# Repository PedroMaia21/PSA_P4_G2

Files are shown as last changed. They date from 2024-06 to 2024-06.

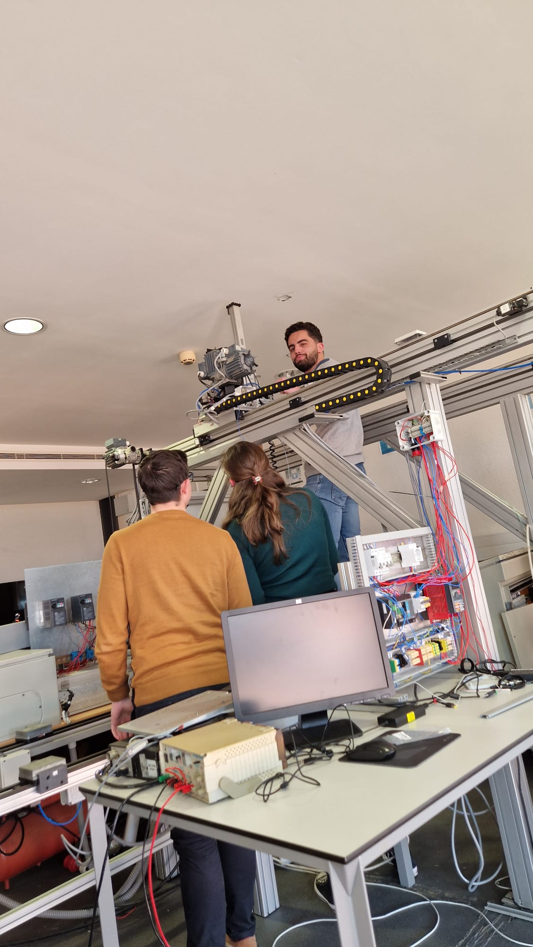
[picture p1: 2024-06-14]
pagina_web/portico24/portico.jpeg

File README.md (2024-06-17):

# PSA_P4_G2
## Descrição
O objetivo principal deste projeto foi realizar o retrofitting de um pórtico cartesiano existente no Laboratório de Sistemas Flexíveis de Produção, trazendo-o de volta ao estado de funcionamento original. Especificamente, procurámos garantir o funcionamento dos eixos Y e Z que anteriormente não estavam operacionais.

### Objetivos do Projeto
 - Avaliação do estado do pórtico cartesiano e identificação dos problemas a resolver.
 - Definição das soluções técnicas a serem implementadas.
 - Execução das modificações e melhorias através do desenvolvimento de um quadro elétrico e da programação de um PLC, um microcontrolador e uma aplicação Web.
 - Realização de testes rigorosos e simulações para validar as melhorias implementadas.

### Resultados Alcançados
 - **Pórtico com todos os eixos funcionais:** O pórtico cartesiano agora possui todos os eixos (X, Y e Z) operacionais.
 - **Novas funcionalidades:** Implementação de controlo remoto via aplicação Web.
 - **Melhorias na performance e funcionamento:** O sistema foi aprimorado para atender melhor às necessidades operacionais futuras.

## Uso
Conecte todos os componentes conforme descrito na documentação.

Carregue o código no PLC e no microcontrolador. (Apenas é necessário editar o nome da rede de internet a usar e a palavra-passe no microcontrolador)

Acesse a aplicação Web para controlar remotamente o pórtico cartesiano. Garanta que o node-red se encontra a correr.

### Contacto
Em caso de estrema necessidade, contactar pedroabmaia@hotmail.com

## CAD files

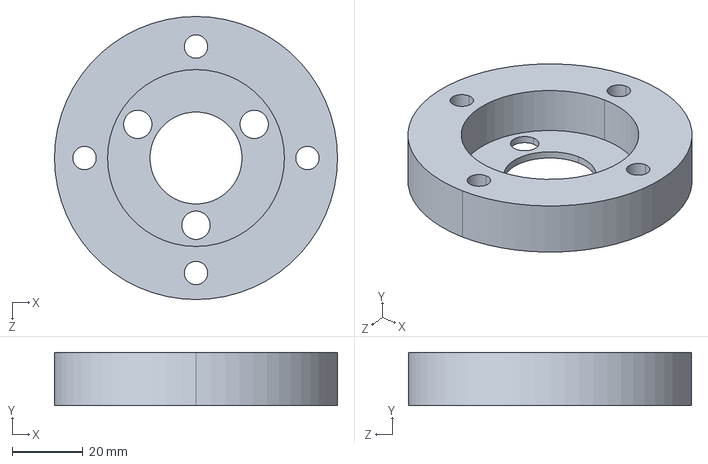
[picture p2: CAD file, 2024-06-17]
projeto_mecânico/Peça encoder.STEP
80.0 x 15.0 x 80.0 mm

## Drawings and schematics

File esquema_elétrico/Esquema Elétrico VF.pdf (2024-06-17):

Título / Frontispício | = 0

3810-1932

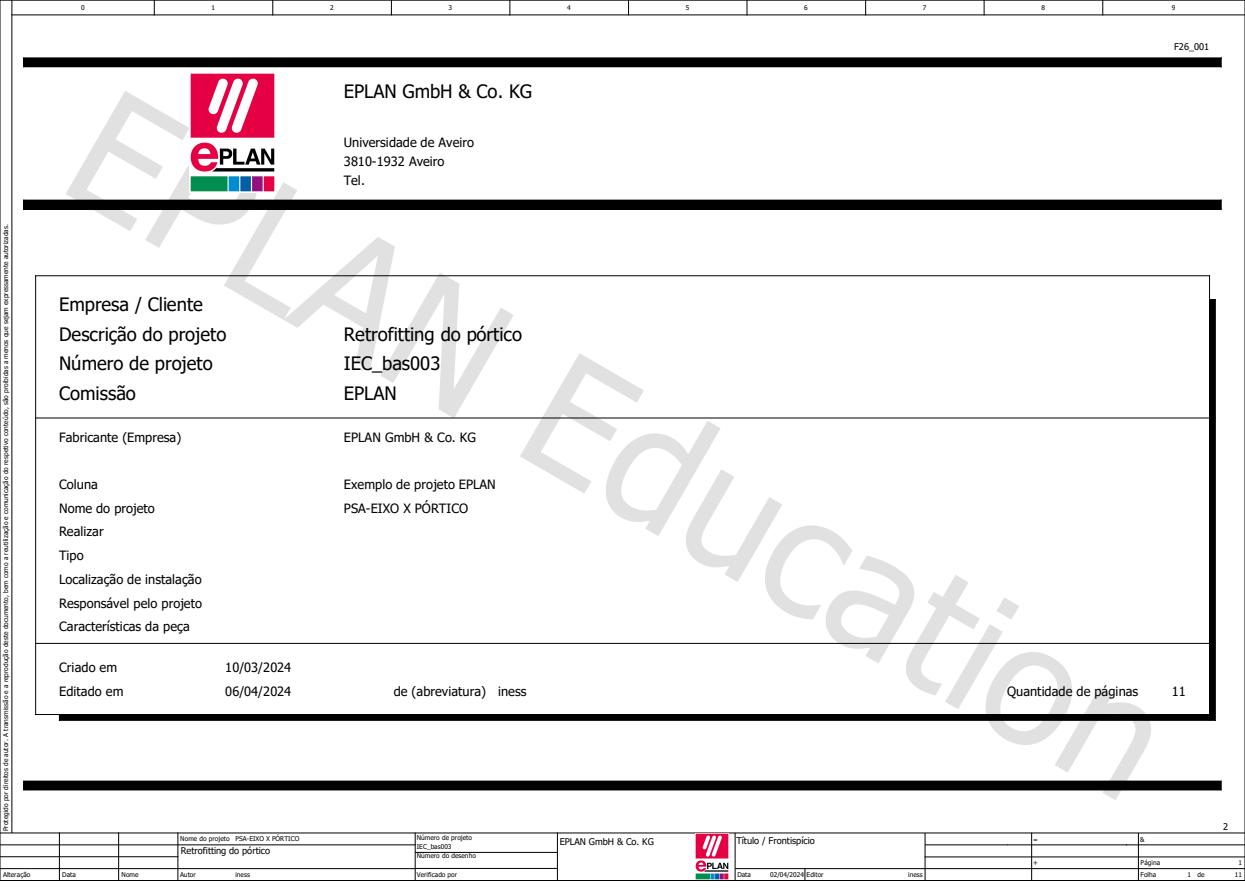
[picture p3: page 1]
Folha; de Retrofitting do pórtico; Editor IEC_bas003 Data; Data; iness 1; Alteração; Nome; EPLAN GmbH & Co. KG; Página; 1 PSA-EIXO X PÓRTICO; Verificado por Nome do projeto; Número do desenho Número de projeto Autor; iness Protegido por direitos de autor. A transmissão e a reprodução deste documento, bem como a reutilização e comunicação do respetivo conteúdo, são proibidas a menos que sejam expressamente autorizadas.; Descrição do projeto; Retrofitting do pórtico; Editado em; IEC_bas003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

EPLAN GmbH & Co. KG

Universidade de Aveiro

Empresa / Cliente
Número de projeto
Comissão

Coluna
Realizar
Tipo
Localização de instalação
Responsável pelo projeto
Características da peça

Exemplo de projeto EPLAN

Quantidade de páginas

Página | Descrição da página | Campo suplementar da página | Data | Editor | X
/1 | | | 02/04/2024 | iness Título / Frontispício | X

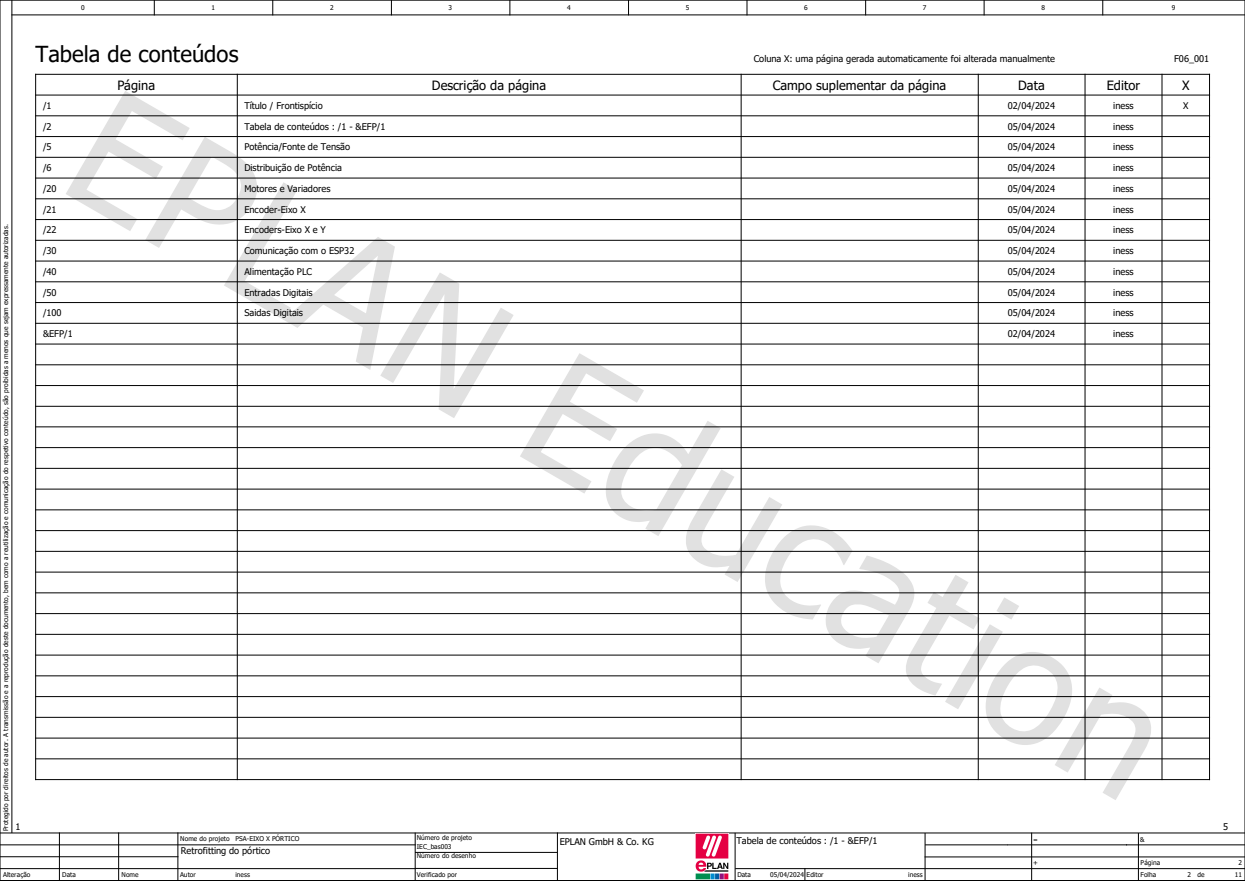
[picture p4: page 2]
Alteração; Nome; Verificado por Nome do projeto; Número do desenho Número de projeto Autor; iness Protegido por direitos de autor. A transmissão e a reprodução deste documento, bem como a reutilização e comunicação do respetivo conteúdo, são proibidas a menos que sejam expressamente autorizadas.

Tabela de conteúdos

Coluna X: uma página gerada automaticamente foi alterada manualmente

/2 | | | 05/04/2024 | iness Tabela de conteúdos : /1 - &EFP/1
/5 | | | 05/04/2024 | iness Potência/Fonte de Tensão
/6 | | | 05/04/2024 | iness Distribuição de Potência
/20 | Motores e Variadores | | 05/04/2024 | iness
/21 | Encoder-Eixo X | | 05/04/2024 | iness
/22 | Encoders-Eixo X e Y | | 05/04/2024 | iness
/30 | Comunicação com o ESP32 | | 05/04/2024 | iness
/40 | Alimentação PLC | | 05/04/2024 | iness
/50 | Entradas Digitais | | 05/04/2024 | iness
/100 | Saidas Digitais | | 05/04/2024 02/04/2024 | iness &EFP/1 iness

EPLAN GmbH & Co. KG | Editor 1 Tabela de conteúdos : /1 - &EFP/1 Data iness | = | Folha de Retrofitting do pórtico 2 PSA-EIXO X PÓRTICO

IEC_bas003 Data | | | | & + Página

5Q1

5F1

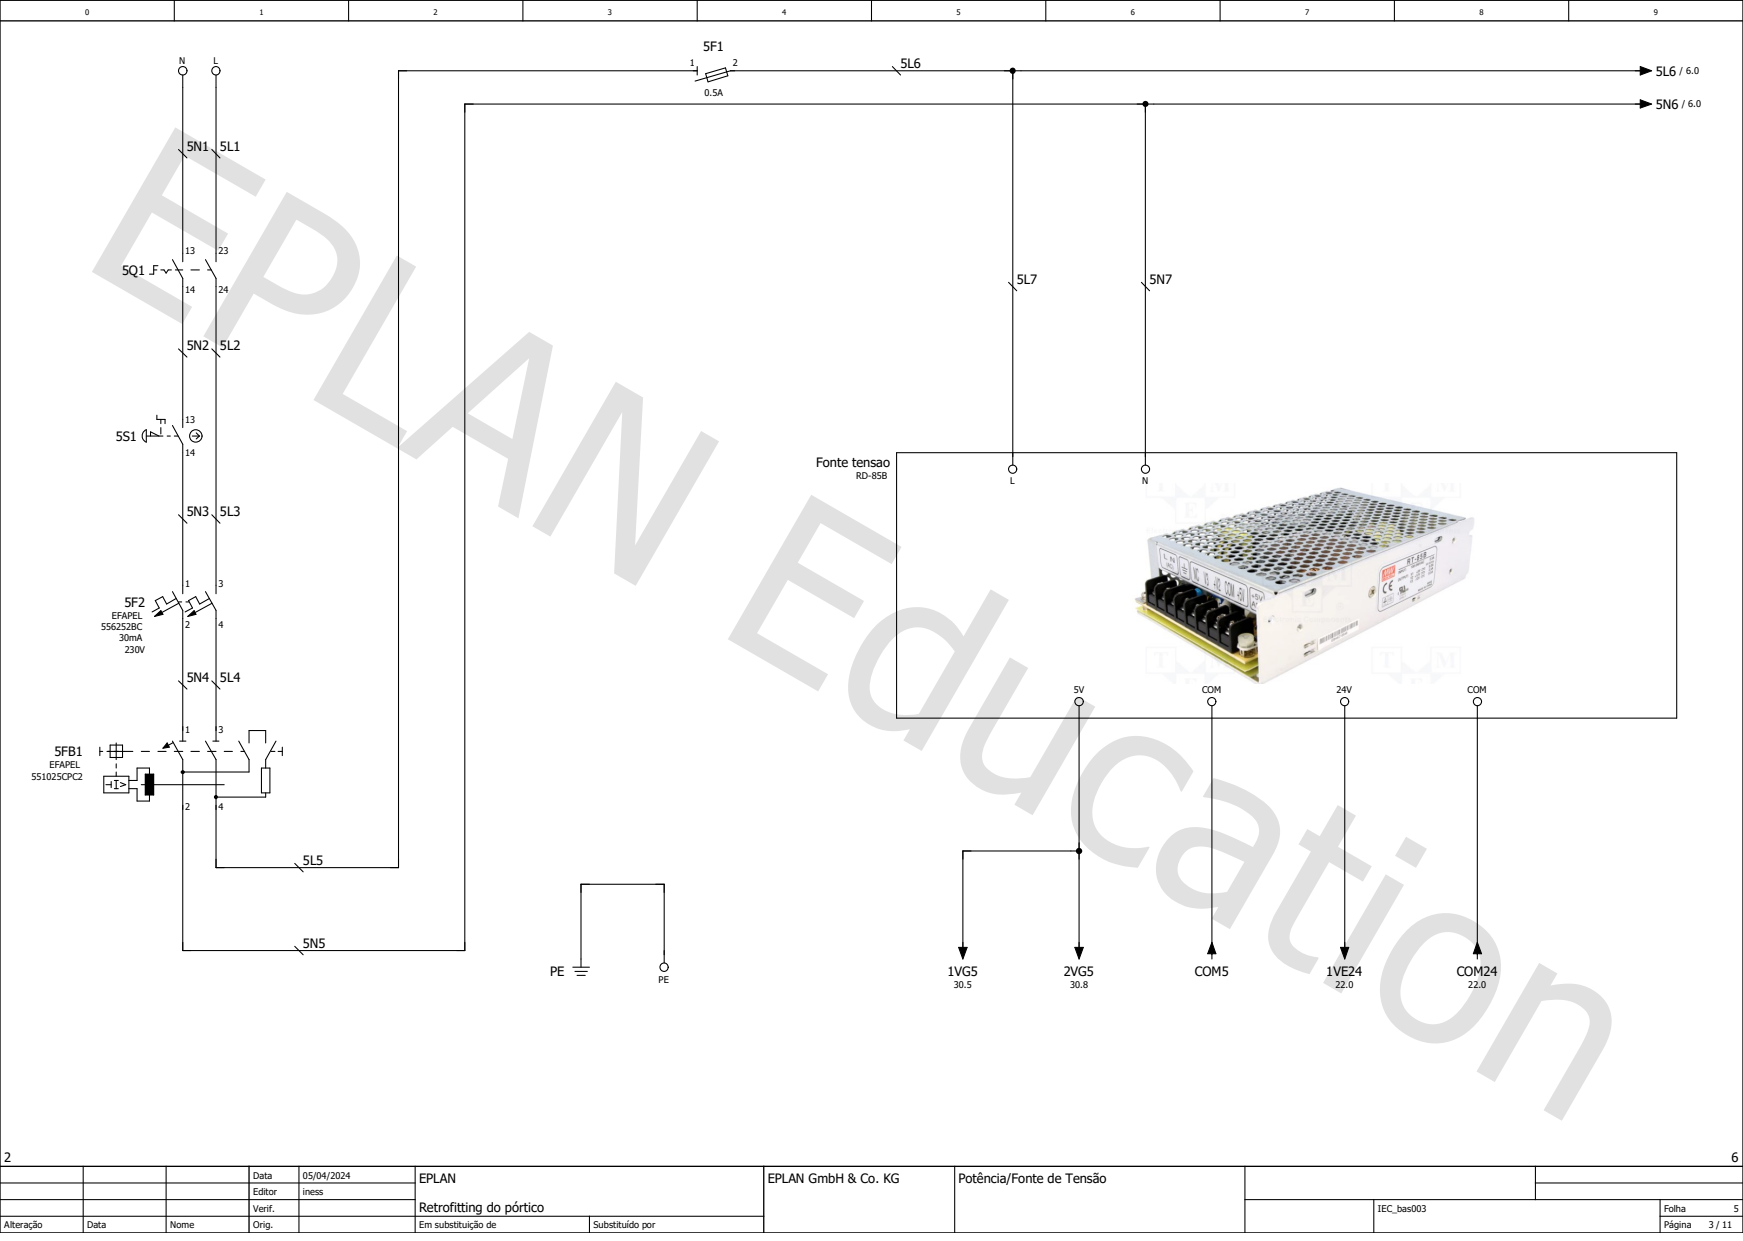
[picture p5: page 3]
Folha Página Retrofitting do pórtico Editor 2; Orig.; IEC_bas003 EPLAN; Verif.; Em substituição de; Fonte tensao RD-85B; COM; 5FB1 EFAPEL; 551025CPC2; 5F2 EFAPEL; 22.0 COM5; COM24

05/04/2024 | Substituído por | EPLAN GmbH & Co. KG | Potência/Fonte de Tensão

Data | iness Data

Alteração | Nome | 3 / 11

6FC1 | /6.1

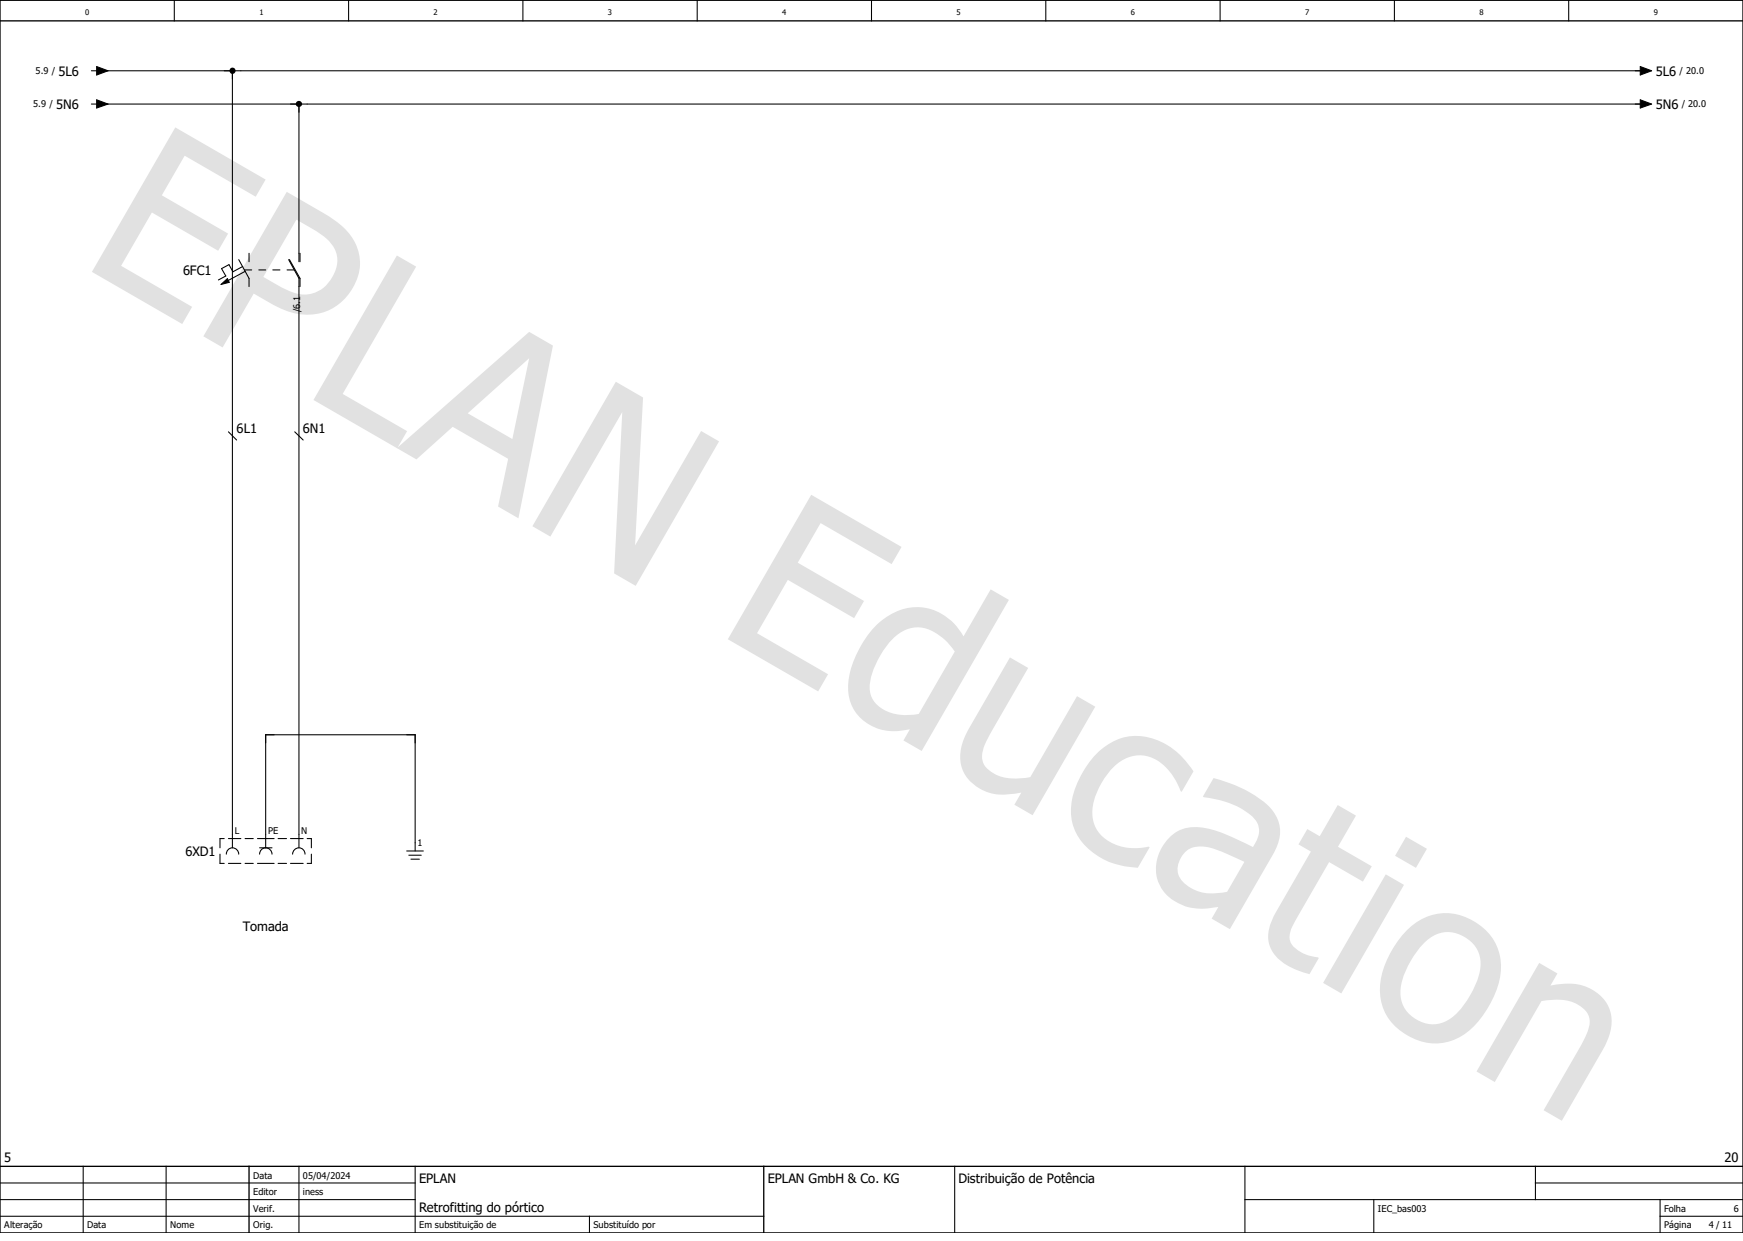
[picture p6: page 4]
Folha Página Retrofitting do pórtico Editor 5; Orig.; IEC_bas003 EPLAN; Verif.; Em substituição de; Tomada

05/04/2024 | Substituído por | EPLAN GmbH & Co. KG | Distribuição de Potência

Data | iness Data

Alteração | Nome | 4 / 11

## -20FC1 EFAPEL

20L1

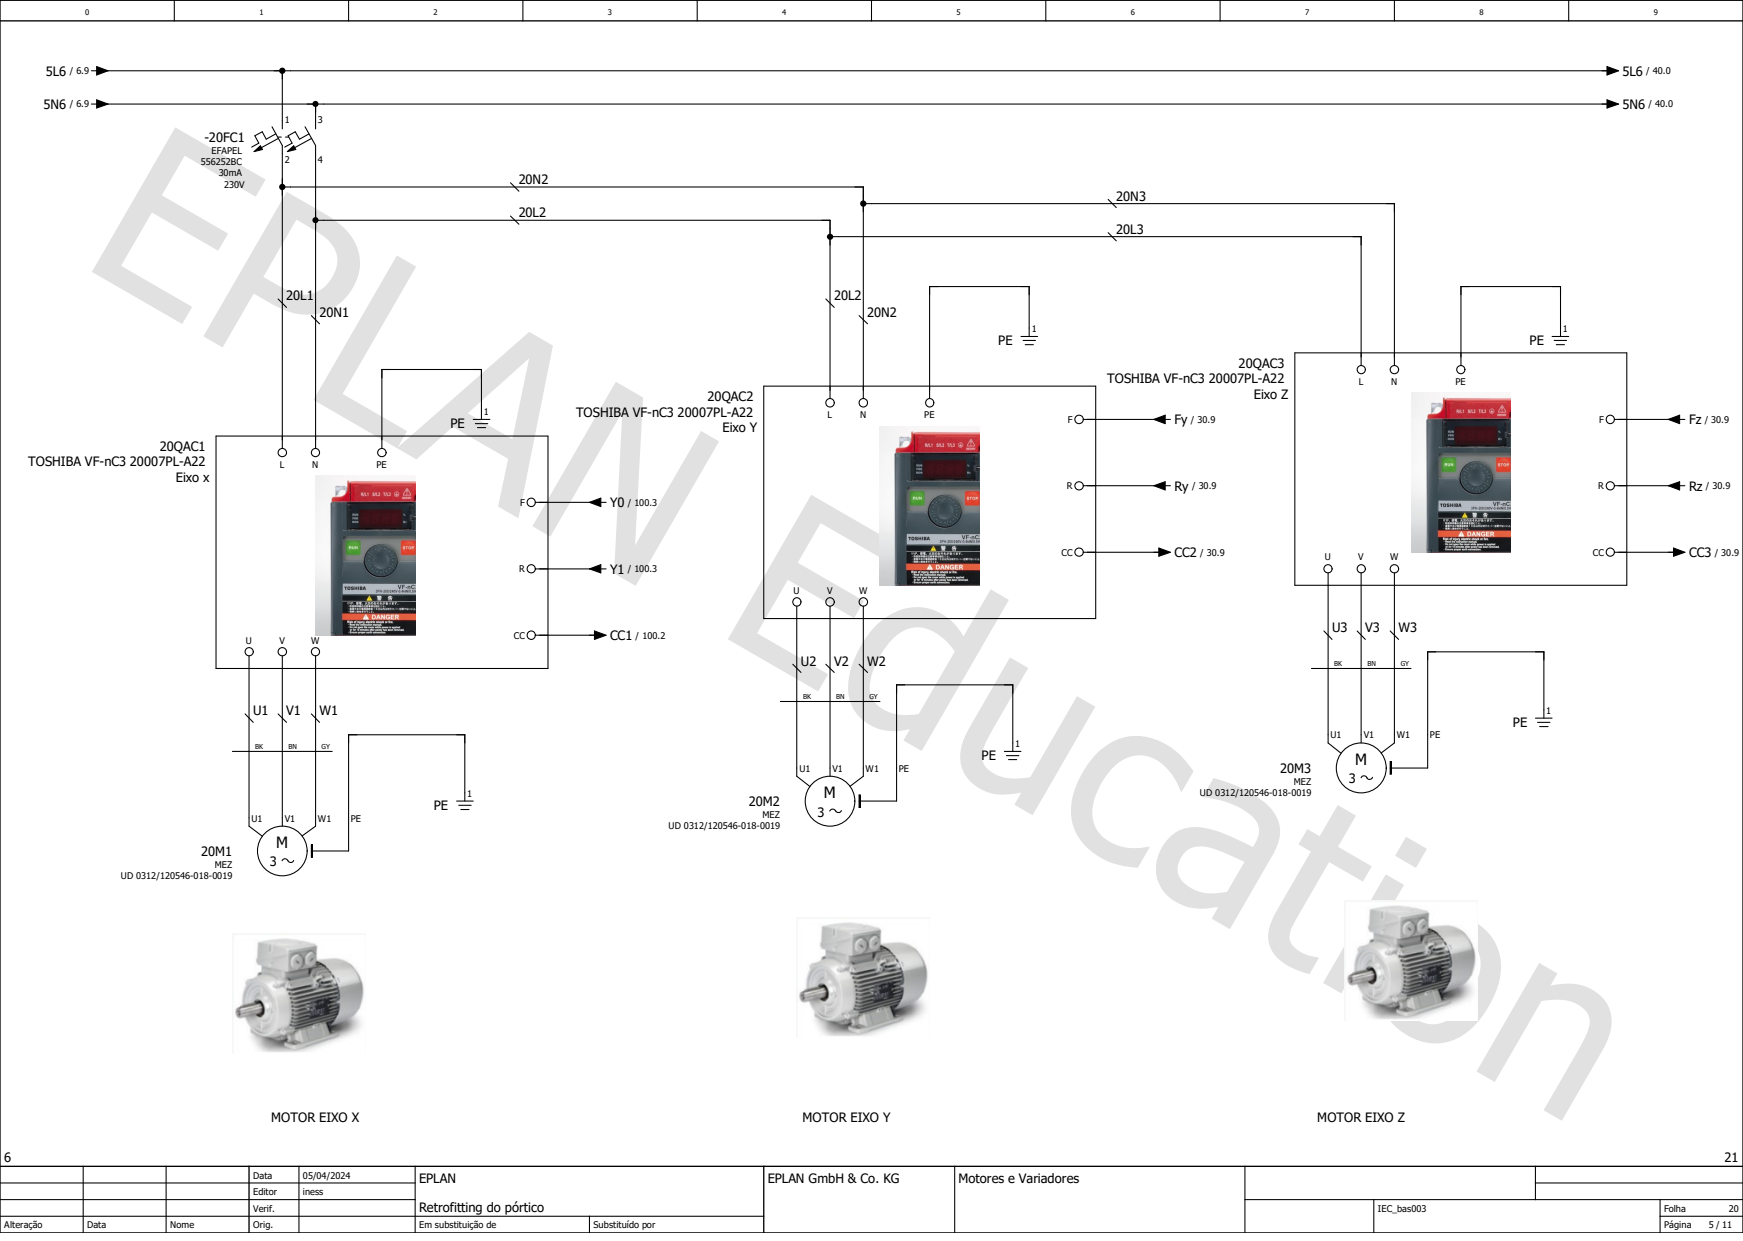
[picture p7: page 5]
Folha Página Retrofitting do pórtico Editor 6; Orig.; IEC_bas003 EPLAN; Verif.; Em substituição de; 5 / 11 MOTOR EIXO X; MOTOR EIXO Y; MOTOR EIXO Z; 20QAC1 TOSHIBA VF-nC3 20007PL-A22; Eixo x; 20M1 MEZ; 20M2 MEZ; 20QAC2 TOSHIBA VF-nC3 20007PL-A22; Eixo Y; 20M3 MEZ; 20QAC3 TOSHIBA VF-nC3 20007PL-A22 Eixo Z

05/04/2024 | Substituído por | EPLAN GmbH & Co. KG | Motores e Variadores

Data | iness Data

Alteração | Nome

2VE24 / 21.9

2VE24 / 21.0

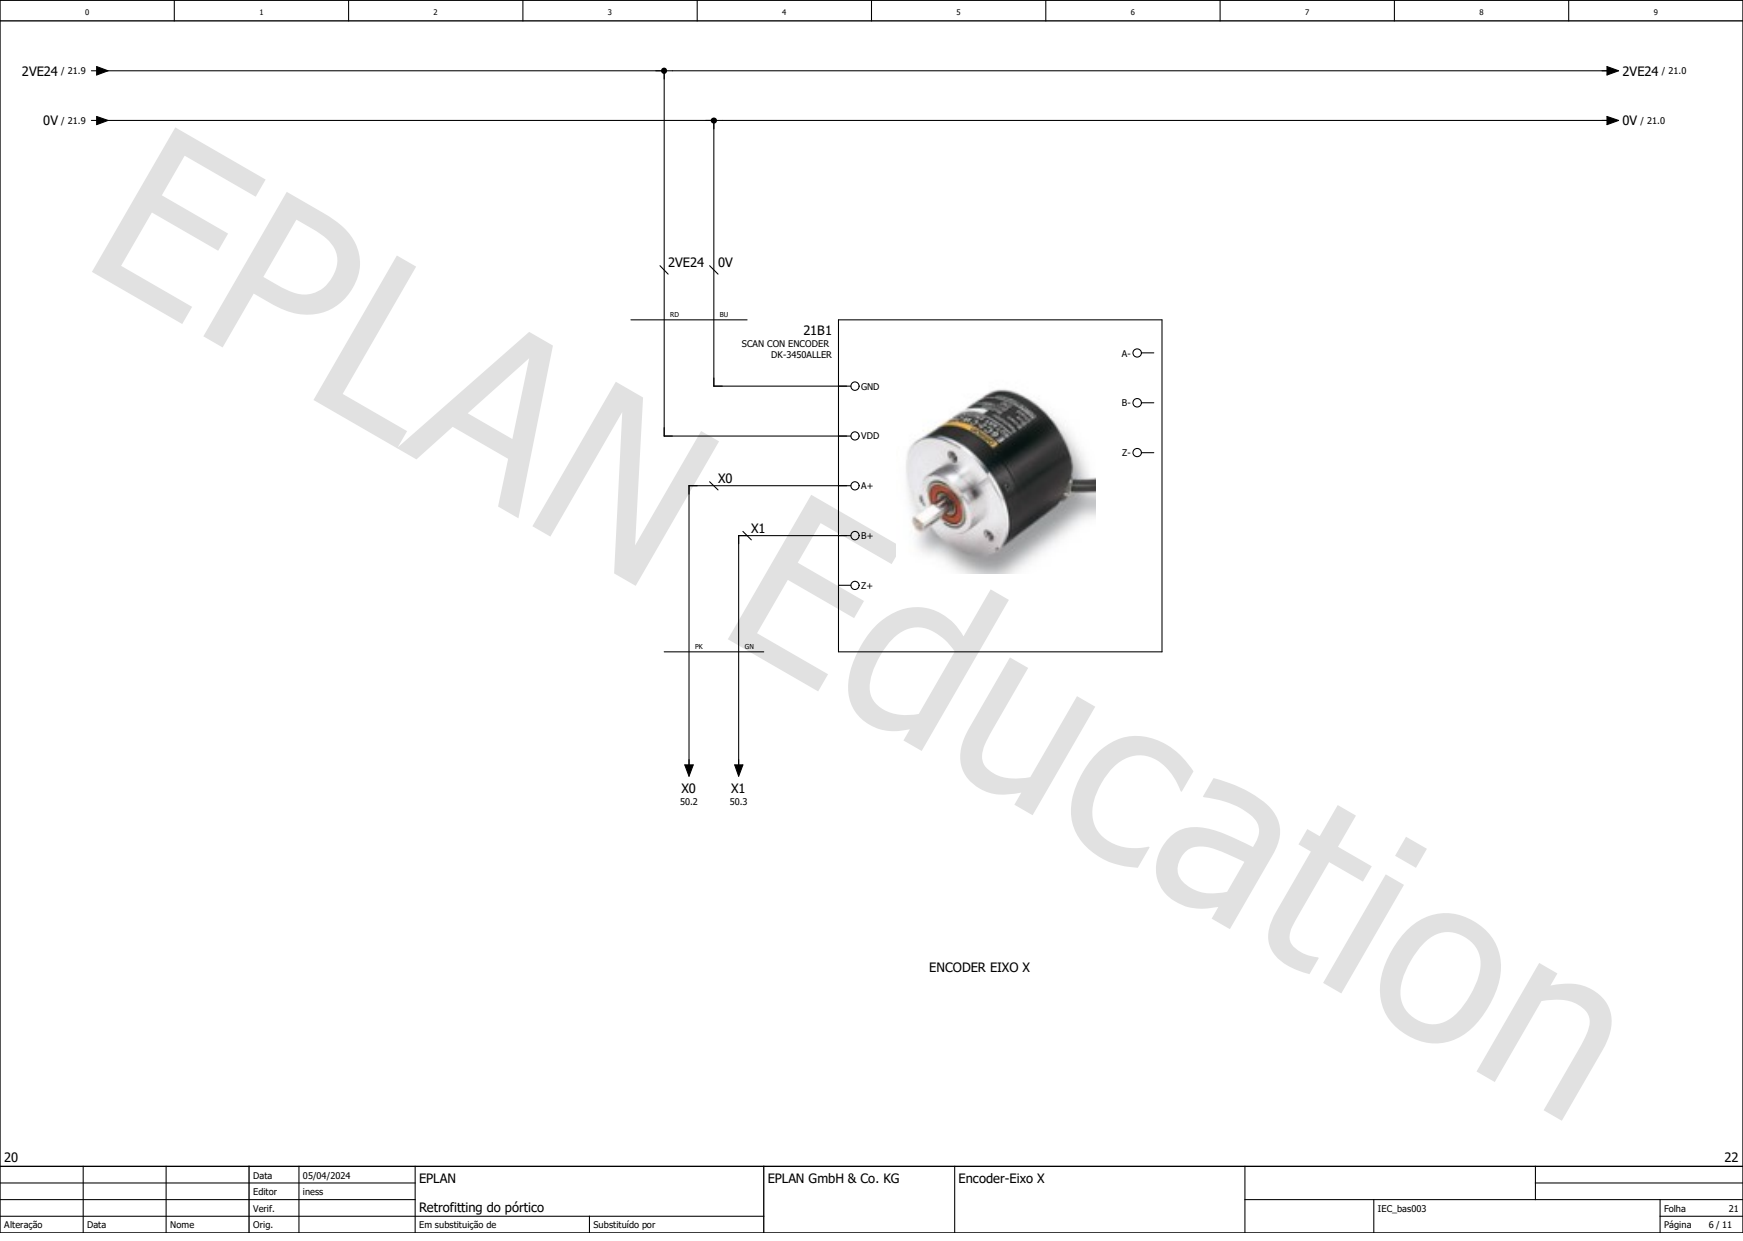
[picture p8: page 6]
Folha Página Retrofitting do pórtico Editor 20; Orig.; IEC_bas003 EPLAN; Verif.; Em substituição de; ENCODER EIXO X; DK-3450ALLER; GND; VDD

21B1 SCAN CON ENCODER

05/04/2024 | Substituído por | EPLAN GmbH & Co. KG | Encoder-Eixo X

Data | iness Data

Alteração | Nome | 6 / 11

## 1VE24 / 5.7 COM 24 / 5.8
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

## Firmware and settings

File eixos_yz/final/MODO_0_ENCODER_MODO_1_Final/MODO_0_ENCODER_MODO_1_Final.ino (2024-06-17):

/*---------------------------------------
Iniciação - bibliotecas WiFi e MQTT
---------------------------------------*/
#include <WiFi.h> //WiFi.h é usado para conectar o ESP32 a uma rede Wi-Fi 
#include <PubSubClient.h> //PubSubClient.h é usada para comunicação MQTT 

/*---------------------------------------
variavéveis
---------------------------------------*/
int y_cima = 13; // cima representa o pin 1 do opto-relé que faz o eixo y ir para cima;
int y_baixo = 4; // baixo representa o pin 2 do opto-relé que faz o eixo y ir para baixo;
int z_frente = 33; // frente representa o pin 3 do opto-relé que faz o eixo z andar para a frente (longe do zero);
int z_tras = 32; // tras representa o pin 4 do opto-relé que faz o eixo z andar para trás (perto do zero);
int ENC_Ay = 16; //Pin1_optocoupler1 ligado ao canal A do encoder y;
int ENC_By= 17; //Pin2_optocoupler1 ligado ao canal B do encoder y;
int fcy_cima = 18;//Pin3_optocoupler1 ligado ao fim de curso de cima;
int fcy_baixo = 19;//Pin4_optocoupler1 ligado ao fim de curso de baixo;
int sref_y = 21; //Pin5_optocoupler1 ligado ao sensor de referência do eixo y;
int ENC_Az = 22; //Pin1_optocoupler1 ligado ao canal A do encoder z;
int ENC_Bz = 23; //Pin2_optocoupler1 ligado ao canal B do encoder z;
int fcz_frente = 25;//Pin3_optocoupler1 ligado ao fim de curso da frente;
int fcz_tras = 26;//Pin4_optocoupler1 ligado ao fim de curso de tras;
int sref_z = 27; //Pin5_optocoupler1 ligado ao sensor de referÊncia do exio z;

volatile int Py= 0; 
volatile int Pz= 0; 

int Modo=2; //Modo de funcionamento 2 significa stand by. Os outros modos são 0 e 1
int concluido; //variável para demonstrar que determinado pedido foi concluído

//Variáveis "intermédias" usadas no loop
int FC_y_cima, FC_y_baixo, SREF_Y, FC_z_frente, FC_z_tras, SREF_Z;

/*---------------------------------------
Funções encoders
---------------------------------------*/
//Função do encoder eixo y
void isr_y() {
  if (digitalRead(ENC_By)) {
    Py ++;
  } else {
    Py --;
  }
  //Serial.print("y: ");  motivo de erro
  //Serial.println(count_Py);
}

//Função do encoder eixo z
void isr_z() {
  if (digitalRead(ENC_Bz)) {
    Pz ++;
  } else {
    Pz --;
  }
  //Serial.print("z: ");
  //Serial.println(count_Pz);
}

/*-------------------------------------------
Conecção WiFi - Depende de telemóvel pessoal
-------------------------------------------*/
const char *SSID = "Rede do Maia"; //nome da rede wifi
const char *PWD = "21_7PabM"; // palavra-passe da rede wifi

/*---------------------------------------
Conecção ao Mqtt Server
---------------------------------------*/
WiFiClient wifiClient; //Estas variáveis estão relacionadas à configuração do cliente MQTT. 
//mqttClient é o cliente MQTT que se conecta ao servidor MQTT definido por mqttServer e mqttPort.
PubSubClient mqttClient(wifiClient); 
char *mqttServer = "193.137.172.20"; 
int mqttPort = 85;
long lastMsg = 0; //Tempo da ultima mensagem
const long interval = 1000; //Intervalo entre mensagens

/*---------------------------------------
Váriavies usadas para o Mqtt Server
---------------------------------------*/
// long last_time=0; <--- Ver se é preciso ou apagar
char data[100]; //Armazenamento de mensagens trocadas
String Command;
int Pdy; //Posião desejada em y e z
int Pdz;

/*---------------------------------------
Conecção ao  WiFi: conecção  do ESP32 à rede Wi-Fi especificada pelos SSID e senha
---------------------------------------*/
void connectToWiFi() {
  WiFi.begin(SSID, PWD);
  while (WiFi.status() != WL_CONNECTED) {
    Serial.print(".");
    delay(500);
  }
  Serial.println("");
  Serial.println("WiFi connected");
  Serial.println("IP address: ");
  Serial.println(WiFi.localIP());
}

/*---------------------------------------
Conecção ao MQTT server: Esta função configura o cliente MQTT para se conectar ao servidor MQTT 
//especificado e define a função de retorno de chamada (callback) que será chamada quando mensagens forem recebidas.
---------------------------------------*/
void setupMQTT() {
  mqttClient.setServer(mqttServer, mqttPort);
  // set the callback function
  mqttClient.setCallback(callback);
}

//Esta função é chamada para reconectar o cliente MQTT se a conexão for perdida. Ele gera um ID de cliente aleatório e se conecta ao servidor MQTT. 
//Em seguida, ele se inscreve em tópicos específicos para receber comandos e dados de sensores.
void reconnect() {
  while (!mqttClient.connected()) {
    Serial.print("Attempting MQTT connection...");
    String clientId = "ESP32Client-"; //criação de um iD aleatório que muda de cada vez que é necessário conectar.
    clientId += String(random(0xffff), HEX);
    if (mqttClient.connect(clientId.c_str())) {
      // subscribe to topic
      Serial.println("connected");
      mqttClient.subscribe("PSA24G2_yzCommand");
    }   
  }
}

/*---------------------------------------
Setting the callbacks for MQTT server: Esta função é chamada sempre que uma mensagem MQTT é recebida. 
//Ele analisa o tópico da mensagem e atualiza as variáveis apropriadas com os dados recebidos.
---------------------------------------*/
void callback(char* topic, byte* payload, unsigned int length) {
  String message;
  for (int i = 0; i < length; i++) {
    message += (char)payload[i];
  }
  if (strcmp(topic,"PSA24G2_yzCommand")==0){
    Command=message; 
  }
  
  //Separação da informação dos eixos  y e z 
  // 1º Passo: Encontrar os índices dos separadores
  int M_Index = Command.indexOf('M');
  int Y_Index = Command.indexOf('Y');
  int Z_Index = Command.indexOf('Z');
  
  // 2º Passo: Extrair as partes das mensagens
  Modo = Command.substring(M_Index+1, M_Index+2).toInt(); //Numero do modo de funcionamento
  String yPart = Command.substring(Y_Index + 1, Y_Index+6);
  String zPart = Command.substring(Z_Index + 1, Z_Index+6);

  //3ºPasso: Coverter valor para inteiro 
  Pdy = yPart.toInt();
  Pdz = zPart.toInt();
  concluido=0; //"Reiniciar" variável

  //"Imprimir os valores de Pdy e Pdz"  <--- Retirar depois
  //Serial.print("yPart: ");
  //Serial.println(Pdy);
  //Serial.print("zPart: ");
  //Serial.println(Pdz);
}

/*---------------------------------------
FUNÇÃO COMUNICAR COM O MQTT
---------------------------------------*/
void sendMQTTMessage(){
  long now = millis();
  if (now - lastMsg > interval) {
    lastMsg = now;
    sprintf(data, "C%iY%iZ%i",concluido,Py,Pz);
    mqttClient.publish("PSA24G2_yzFeedback",data);
  }
}

void setup() {
  //Saídas - variadores
  pinMode(y_cima,OUTPUT); 
  pinMode(y_baixo,OUTPUT);
  pinMode(z_frente,OUTPUT);
  pinMode(z_tras,OUTPUT);

  //Entradas - sensores
  pinMode(fcy_cima,INPUT);
  pinMode(fcy_baixo,INPUT);
  pinMode(sref_y,INPUT);
  pinMode(fcz_frente,INPUT);
  pinMode(fcz_tras,INPUT);
  pinMode(sref_z,INPUT);

  //Iniciakização do relé (apesar de estar HIGH como este funciona ao contrário na verdade é LOW)
  digitalWrite(y_cima, HIGH);
  digitalWrite(y_baixo,HIGH);
  digitalWrite(z_frente,HIGH);
  digitalWrite(z_tras,HIGH);
  
  Serial.begin (19200);   //<--- Retirar depois

  // Set encoder pins and attach interrupts
  pinMode(ENC_Ay, INPUT);
  pinMode(ENC_By, INPUT);
  attachInterrupt(digitalPinToInterrupt(ENC_Ay), isr_y, RISING);
  pinMode(ENC_Az, INPUT);
  pinMode(ENC_Bz, INPUT);
  attachInterrupt(digitalPinToInterrupt(ENC_Az), isr_z, RISING);

  //Connect to Wifi and MQTT
  connectToWiFi();
  setupMQTT();
}

void loop() {
  if (!mqttClient.connected()) {
    reconnect();
  }
  mqttClient.loop();

  FC_y_baixo=digitalRead(fcy_baixo); //Fim de curso é normalmente fechado e optocoupler inverte, o que faz que quando toca no fc fica a 3.3V
  SREF_Y=!digitalRead(sref_y);       //Sensor de ref é normalmente aberto, e o optocoupler inverte, o que faz que quando toca no sref fica a 0V
  FC_z_tras=digitalRead(fcz_tras); 
  SREF_Z=!digitalRead(sref_z);
  static int lastPy = 0; // variáveis de visualização - apagar mais tarde
  static int lastPz = 0;

  if (Modo == 0){
    /*---------------------------------------
    Modo 0
    ---------------------------------------*/

    concluido=0; // Inicialização da variável
    digitalWrite(y_cima,LOW);  //ligar o motor para andar para baixo
    while (!SREF_Y) {
      FC_y_baixo=digitalRead(fcy_baixo);
      SREF_Y=!digitalRead(sref_y);
      Serial.println(SREF_Y);
      if(Py != lastPy){   // Visualização - apagar mais tarde
        Serial.print("Y: ");
        Serial.println(Py);
        lastPy = Py;
      }

      if(FC_y_baixo){
        digitalWrite(y_cima,HIGH); // Inverter sentido se sensor abrir (entrada a 3v3)
        digitalWrite(y_baixo,LOW);
        
        while (!SREF_Y) {
          SREF_Y=!digitalRead(sref_y);
          sendMQTTMessage();
          
          if(Py != lastPy){   // Visualização - apagar depois
            Serial.print("Y: ");
            Serial.println(Py);
            lastPy = Py;
          }
        }
      }
      sendMQTTMessage(); // função enviar sms MQTT
    }

    digitalWrite(y_cima,HIGH);    //Conclusão do modo 0 em y
    digitalWrite(y_baixo,HIGH);
    Py=0;

    digitalWrite(z_tras,LOW);   //Início do modo 0 em z, andar para trás
    while (!SREF_Z){
      FC_z_tras=digitalRead(fcz_tras);
      SREF_Z=!digitalRead(sref_z);

      if(Pz != lastPz){   //Visualização - apagar depois
        Serial.print("Z: ");
        Serial.println(Pz);
        lastPz = Pz;
      }

      if(FC_z_tras){
        digitalWrite(z_tras,HIGH);  //Inverter sentido - passa a andar para a frente
        digitalWrite(z_frente,LOW);

        while (!SREF_Z) {
          SREF_Z = !digitalRead(sref_z);// pin 27
          sendMQTTMessage(); // função enviar sms MQTT
          
          if(Pz != lastPz){ //Visualização - apagar depois
            Serial.print("Z: ");
            Serial.println(Pz);
            lastPz = Pz;
          }
        }
      }
      sendMQTTMessage(); // função enviar sms MQTT
    }
    digitalWrite(z_tras,HIGH);  //desligar motores
    digitalWrite(z_frente,HIGH);    
    Pz=0;
    
    Modo=2; // modo stand-by
    concluido=1;  //enviar mensagem de concluído após 2 segundos
    delay(2000);
    sendMQTTMessage();
  
  } else if(Modo==1) {
    /*---------------------------------------
    Modo 1 
    ---------------------------------------*/

    Serial.println(Pdy); //Visualização - apagar depois
    Serial.println(Pdz);

    //Eixo y
    while(Py<Pdy-20 && Modo==1){
      FC_y_baixo=digitalRead(fcy_baixo);
      FC_y_cima=digitalRead(fcy_cima);
      
      digitalWrite(y_cima,LOW);   //Sentido positivo de baixo para cima
      sendMQTTMessage(); // função enviar sms MQTT
      
      if(Py != lastPy){   //Visualização - apagar depois
        Serial.print("Y: ");
        Serial.println(Py);
        lastPy = Py;
      }

      if(FC_y_cima || FC_y_baixo){    //Evitar exceder os limites - lança um erro
        digitalWrite(y_cima,HIGH);    //Desliga o motor
        digitalWrite(y_baixo,HIGH);
        Modo = 0; //Volta para o ponto zero para recalibrar
        concluido=2;  //O valor 2 indica que foi concluído com erro
        delay(2000);
        sendMQTTMessage();
        break;
      }
    }
    while (Py>Pdy+20 && Modo==1){
      digitalWrite(y_baixo,LOW);  //sentido negativo - para baixo
      
      FC_y_baixo=digitalRead(fcy_baixo);
      FC_y_cima=digitalRead(fcy_cima);
      sendMQTTMessage(); // função enviar sms MQTT
      
      if(Py != lastPy){  //Visualização - apagar depois
        Serial.print("Y: ");
        Serial.println(Py);
        lastPy = Py;
      }
      
      if(FC_y_cima || FC_y_baixo){ // Para garantir que não se ultrapassam os limites dos sensores de fim de curso
        digitalWrite(y_cima,HIGH);  //desligar o motor
        digitalWrite(y_baixo,HIGH);
        Modo =0;  //voltar ao zero
        concluido=2;  //concluído com erro
        delay(2000);
        sendMQTTMessage();
        break;
      }
    }

    digitalWrite(y_cima,HIGH); //desligar o motor
    digitalWrite(y_baixo,HIGH);

    //Eixo z
    while(Pz<Pdz-20 && Modo==1){
      FC_z_frente=digitalRead(fcz_frente);
      FC_z_tras=digitalRead(fcz_tras);
      digitalWrite(z_tras,LOW); //sentido positivo - da frente para trás
      sendMQTTMessage(); // função enviar sms MQTT
      
      if(Pz != lastPz){   //Visualização - apagar depois
        Serial.print("Z: ");
        Serial.println(Pz);
        lastPz = Pz;
      }
      
      if(FC_z_frente || FC_z_tras){ //Erro
        digitalWrite(z_frente,HIGH);  //DEsliga o motor
        digitalWrite(z_tras,HIGH);
        Modo =0;  //Tenta voltar ao zero
        concluido=2;  //Indica o erro
        delay(2000);
        sendMQTTMessage();
        break;
      }
    }

    while(Pz>Pdz+20 && Modo==1){
      FC_z_frente=digitalRead(fcz_frente);
      FC_z_tras=digitalRead(fcz_tras);
      digitalWrite(z_frente,LOW); // sentido negativo - para a frente
      sendMQTTMessage(); // função enviar sms MQTT
      
      if(Pz != lastPz){ //Visualização - apagar depois
        Serial.print("Z: ");
        Serial.println(Pz);
        lastPz = Pz;
      }
      
      if(FC_z_frente || FC_z_tras){ //caso de erro
        digitalWrite(z_frente,HIGH);  //desliga o motor
        digitalWrite(z_tras,HIGH);
        Modo =0;  //volta para o zero
        concluido=2;  //mensagem de erro
        delay(2000);
        sendMQTTMessage();
        break;
      }
    }
    
    digitalWrite(z_frente,HIGH); //desliga o motor
    digitalWrite(z_tras,HIGH); 
    
    if (concluido !=2 ) { //caso não haja erro
    Modo=2;   //modo de stand-by
    concluido=1;  //mensagem de conclusão
    delay(2000);
    sendMQTTMessage();
    }
  }
} //fim do loop

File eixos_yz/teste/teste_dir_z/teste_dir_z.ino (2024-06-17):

int z0 = 32; // Pino de saída para o controlo do motor 
int z1 = 33; // Pino de saída para o controlo do motor 
int ENC_Az = 22; // Pino de entrada do encoder A eixo Z
int ENC_Bz = 23; // Pino de entrada do encoder B eixo Z
int in_opto2_3 = 25; // Pino de entrada do sensor optoacoplador 3
int in_opto2_4 = 26; // Pino de entrada do sensor optoacoplador 4
int in_opto2_5 = 27; // Pino de entrada do sensor optoacoplador 5
int frente = 14; // Pino de entrada para o botão "frente"
int tras = 15; // Pino de entrada para o botão "tras"
int zero = 18; // Pino de entrada para o botão "zero"
int dir = 0; // Variável para armazenar a direção do movimento
int maxpz = 0; // Variável para armazenar a posição máxima positiva
int maxnz = 0; // Variável para armazenar a posição máxima negativa
int Pz = 0; // Variável para armazenar a posição atual do encoder Z

// Função de interrupção para o encoder Z
void isr_z() {
  if (digitalRead(ENC_Bz)) { // Se o pino B do encoder Z estiver em HIGH
    Pz++; // Incrementa a posição do encoder Z
  } else {
    Pz--; // Decrementa a posição do encoder Z
  }
}

void setup() {
  // Configuração dos pinos como entradas ou saídas
  pinMode(frente, INPUT); // Configura o pino do botão "frente" como entrada
  pinMode(tras, INPUT); // Configura o pino do botão "tras" como entrada
  pinMode(in_opto2_3, INPUT); // Configura o pino do sensor optoacoplador 3 como entrada
  pinMode(in_opto2_4, INPUT); // Configura o pino do sensor optoacoplador 4 como entrada
  pinMode(in_opto2_5, INPUT); // Configura o pino do sensor optoacoplador 5 como entrada
  pinMode(ENC_Az, INPUT); // Configura o pino do encoder A eixo Z como entrada
  pinMode(ENC_Bz, INPUT); // Configura o pino do encoder B eixo Z como entrada
  pinMode(z0, OUTPUT); // Configura o pino do motor Z0 como saída
  pinMode(z1, OUTPUT); // Configura o pino do motor Z1 como saída

  // Inicializa os motores desligados
  digitalWrite(z0, HIGH);
  digitalWrite(z1, HIGH);

  // Configura a interrupção para o encoder Z
  attachInterrupt(digitalPinToInterrupt(ENC_Az), isr_z, RISING);
  Serial.begin(9600); 

void loop() {
  // Se o botão "frente" for pressionado
  if (digitalRead(frente)) {
    digitalWrite(z0, LOW); // Liga o pino Z0
    dir = 1; // Define a direção como positiva
    // Continua movendo-se até que um dos sensores optoacopladores 3 ou 4 sejam acionados
    while (!(digitalRead(in_opto2_3) || digitalRead(in_opto2_4))) {
      Serial.println(Pz); // Imprime a posição atual do encoder Z
    }
    maxpz = Pz; // Armazena a posição máxima positiva
    digitalWrite(z0, HIGH); // Desliga o pino Z0
  }

  delay(1000); // Espera 1 segundo

  // Se o botão "tras" for pressionado
  if (digitalRead(tras)) {
    digitalWrite(z1, LOW); // Liga o pino Z1
    dir = 0; // Define a direção como negativa
    // Continua movendo-se até que um dos sensores optoacopladores 3 ou 4 sejam acionados
    while (!(digitalRead(in_opto2_3) || digitalRead(in_opto2_4))) {
      Serial.println(Pz); // Imprime a posição atual do encoder Z
    }
    maxnz = Pz; // Armazena a posição máxima negativa
    digitalWrite(z1, HIGH); // Desliga o pino Z1
  }

  // Se o botão "zero" for pressionado
  if (digitalRead(zero)) {
    if (dir == 1) {
      digitalWrite(z1, LOW); // Liga o pino Z1 se a direção for positiva
    } else {
      digitalWrite(z0, LOW); // Liga o pino Z0 se a direção for negativa
    }
    // Continua movendo até que o sensor optoacoplador 5 seja acionado
    while (digitalRead(in_opto2_5)) {
      Serial.println(Pz); // Imprime a posição atual do encoder Z
    }
    // Desliga ambos os motores
    digitalWrite(z0, HIGH);
    digitalWrite(z1, HIGH);
  }

  delay(1000); // Espera 1 segundo
}

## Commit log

2024-06-11 Imported flows for x axis
2024-06-14 Added json flows for the web page
2024-06-17 Added the changed Node-Red flows
2024-06-17 Added the electric schematic
2024-06-17 Added the y and z axis ino codes
2024-06-17 Added the step file for the encoder support
    [Peça encoder.STEP]
2024-06-17 Added the ladder files for the x axis
2024-06-17 Added de developed report
